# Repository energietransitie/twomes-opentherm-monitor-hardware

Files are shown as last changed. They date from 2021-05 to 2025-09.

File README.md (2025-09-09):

# Twomes OpenTherm Monitor Shield hardware

This repository contains the open hardware design files for the Twomes OpenTherm Monitor device, consisting of:
* a Twomes OpenTherm Monitor Shield with a [WeMos D1 Mini shield](https://www.wemos.cc/en/latest/d1_mini_shield/index.html) form factor, to be placed on;
* a WeMos D1 Mini board, such as the [LilyGO TTGO T7 Mini32 V1.3 ESP32](https://github.com/LilyGO/ESP32-MINI-32-V1.3). 

The OpenTherm Monitor Shield is connected via one pluggable terminal block with screws to connect one wire pair leading to a [boiler that supports OpenTherm](https://www.otgw.tclcode.com/matrix.cgi#boilers) and via another one pluggable terminal block with screws to connect another wire pair leading to a [thermostat that supports OpenTherm](https://www.otgw.tclcode.com/matrix.cgi#thermostats). The Twomes OpenTherm Monitor can upload this measurement data to a Twomes server via Wi-Fi using secure HTTPS.

N.B. This is device  is NOT an OpenTherm gateway; it only monitors OpenTherm traffic and it cannot insert OpenTherm commands to the boiler or thermostat.

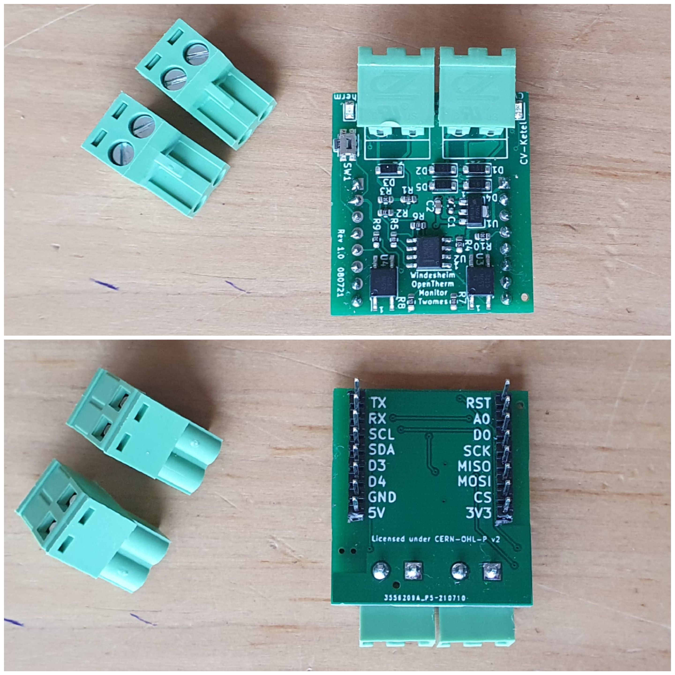
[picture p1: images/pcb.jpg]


## Table of contents
* [General info](#general-info)
* [Producing](#producing)
* [Developing](#developing) 
* [Features](#features)
* [Status](#status)
* [License](#license)
* [Citation](#citation)
* [Credits](#credits)

## General info
This repository contains the open hardware designs files for the Twomes OpenTherm Monitor device, It also includes a `docs` folder with recent printouts of the [schematics](./docs/twomes-opentherm-monitor-hardware-sch-v2.0.pdf) and [PCB layout](./docs/twomes-opentherm-monitor-hardware-pcb-v2.0.pdf). 

The associated firmware that you can run on this device can be found in [this repository](https://github.com/energietransitie/twomes-opentherm-monitor-firmware).

## Producing

### Printed Ciruit Board
To fabricate the printed circuit board you can use various PCB services. 

The folder [pcb/jlcpcb](./pcb/jlcpcb) includes all exported files needed to have the PCBs manufactured by [JLCPCB](https://www.jlcpcb.com). Upload the [zipped gerber files](./pcb/jlcpcb/gerber/gerber-OpenThermMonitorTwomes.zip) to the [JLCPCB quote page](https://cart.jlcpcb.com/quote), select the amount of PCBs and a colour for the silkscreen. All other options can be left on default. If SMT assembly is desired, also select this option before ordering. This will take you to a page where the BOM and POS file can be uploaded. Use the files [BOM-TwomesGateway.csv](./pcb/jlcpcb/assembly/BOM-Twomes-OpenTherm-Monitor.csv) and [CPL-TwomesGateway.csv](./pcb/jlcpcb/assembly/CPL-Twomes-OpenTherm-Monitor.csv).

N.B. The pluggable terminal blocks we used (see [features](#features) are not listed the BOM-*.csv file; they need to be ordered separately other services and soldered manually.

### Enclosure
To fabricate the enclosure you can use your own 3D printer or use a 3D printing service. 

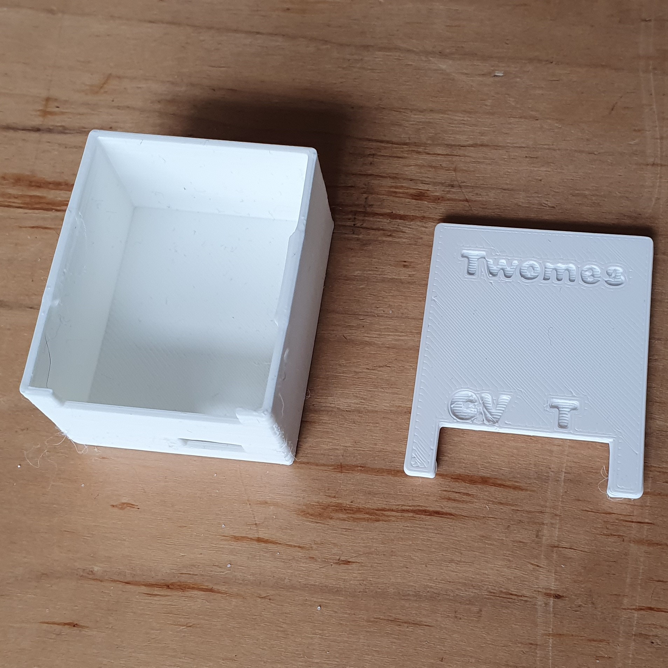
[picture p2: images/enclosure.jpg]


The folder [enclosure/fabrication](./enclosure/fabrication) contains exported STL files for the [case](./enclosure/fabrication/twomes-opentherm-monitor-enclosure-case.stl) and [lid](./enclosure/twomes-opentherm-monitor-enclosure-lid.stl) of the Twomes OpenTherm Monitor. The STL files can be imported into any slicer and turned into G-Code for a 3D printer.

## Developing

### Printed Circuit Board
To change the hardware design of the PCB, you need:
* [KiCad](https://www.kicad.org/download/) installed to change te PCB design. 

The KiCad source files of the PCB can be found in the folder [pcb](./pcb).

To convert the PCBs into a format suitable for fabrication, consult the webpage of your PCB manufacturer of choice. For example, see the [JLCPCB guide on how to export Gerbers](https://support.jlcpcb.com/article/149-how-to-generate-gerber-and-drill-files-in-kicad) and the  [JLCPCB guide how to export the BOM and POS files](https://support.jlcpcb.com/article/84-how-to-generate-the-bom-and-centroid-file-from-kicad). You may also use a KiCad plug-in for this purpose such as [kicad-jlcpcb-tools](https://github.com/Bouni/kicad-jlcpcb-tools).

### Enclosure
To change the hardware design of the enclosure, you need either:
* [Autodesk Fusion 360](https://www.kicad.org/download/) installed (Autodesk provides 30 day free trials and [free one-year educational access](https://www.autodesk.com/education/edu-software/overview?sorting=featured&filters=individual) to its products and services for eligible students, teachers and research staff); 
* or [FreeCAD](https://www.freecadweb.org/), an open source alternative.

The source files of the enclosure can be found in the folder [enclosure](./enclosure). We include both .f3d source files and .step source files we obtained after conversion.

## Features
The Twomes OpenTherm Monitor Shield is a [WeMos D1 Mini shield](https://www.wemos.cc/en/latest/d1_mini_shield/index.html) that features the following main hardware components:
* two terminal blocks [CTB9209/2](https://nl.farnell.com/camdenboss/ctb9209-2/terminal-block-pluggable-2pos/dp/2493642), pluggable into terminal block headers [CTB9359/2](https://nl.farnell.com/camdenboss/ctb9359-2/terminal-block-header-2pos-th/dp/2493694) (one for thermostat, one for boiler), each with two positions;
* two optocouplers that electrically separate the OpenTherm circuit on the shield from the monitoring logic on the shield and the main board: the OpenTherm communication between thermostat and boiler still works even if the main board receives no power via its micro USB port or has crashed;
* recessed button that is positioned behind a pinhole in the device enclosure, which allows the end-user to do a Wi-Fi reset.

To-do:
* change design and JLCPCB files to take advantage of the new [one-sided hand-soldering option for through-hole parts](https://jlcpcb.com/smt-assembly) for the pluggable terminal blocks `J1` and `J2` and the pin headers `P1` and `P2`;

## Status
Project is: _in progress_

## License
The hardware designs in this repository are available under the [CERN-OHL-P v2 license](./LICENSE), Copyright 2022 [Research group Energy Transition, Windesheim University of Applied Sciences](https://windesheim.nl/energietransitie)

## Citation

If you use this repository in your research or work, please cite the following pre-print, which describes the overall NeedForHeat DataGear system of which this repository is a part:

> Ter Hofte, H., & van Ravenzwaaij, N. (2025). *NeedForHeat DataGear: An Open Monitoring System to Accelerate the Residential Heating Transition*. arXiv preprint arXiv:2509.06927. https://doi.org/10.48550/arXiv.2509.06927

**Note:** This is a pre-print submitted on 8 Sep 2025 and has not yet been peer-reviewed. For the full paper, see [https://arxiv.org/abs/2509.06927](https://arxiv.org/abs/2509.06927).

## Credits
This open hardware design is a collaborative effort of:
* Marco Winkelman · [@MarcoW71](https://github.com/MarcoW71)
* Sjors Smit · [@Shorts1999](https://github.com/Shorts1999)

Thanks also go to:
* Henri ter Hofte · [@henriterhofte](https://github.com/henriterhofte)
We use and gratefully acknowlegde the efforts of the makers of the following designs:

* [KiCad Libraries](https://kicad.github.io/), by the KiCad Development Team, licensed under [an adapted version of the CC-BY-SA 4.0 License](https://www.kicad.org/libraries/license/)
* [Opentherm-monitor](https://www.domoticaforum.eu/uploaded/bwired/Open-Termostaat.pdf). In <i>Elektuur, 7-8/2001, pp. 22-23.

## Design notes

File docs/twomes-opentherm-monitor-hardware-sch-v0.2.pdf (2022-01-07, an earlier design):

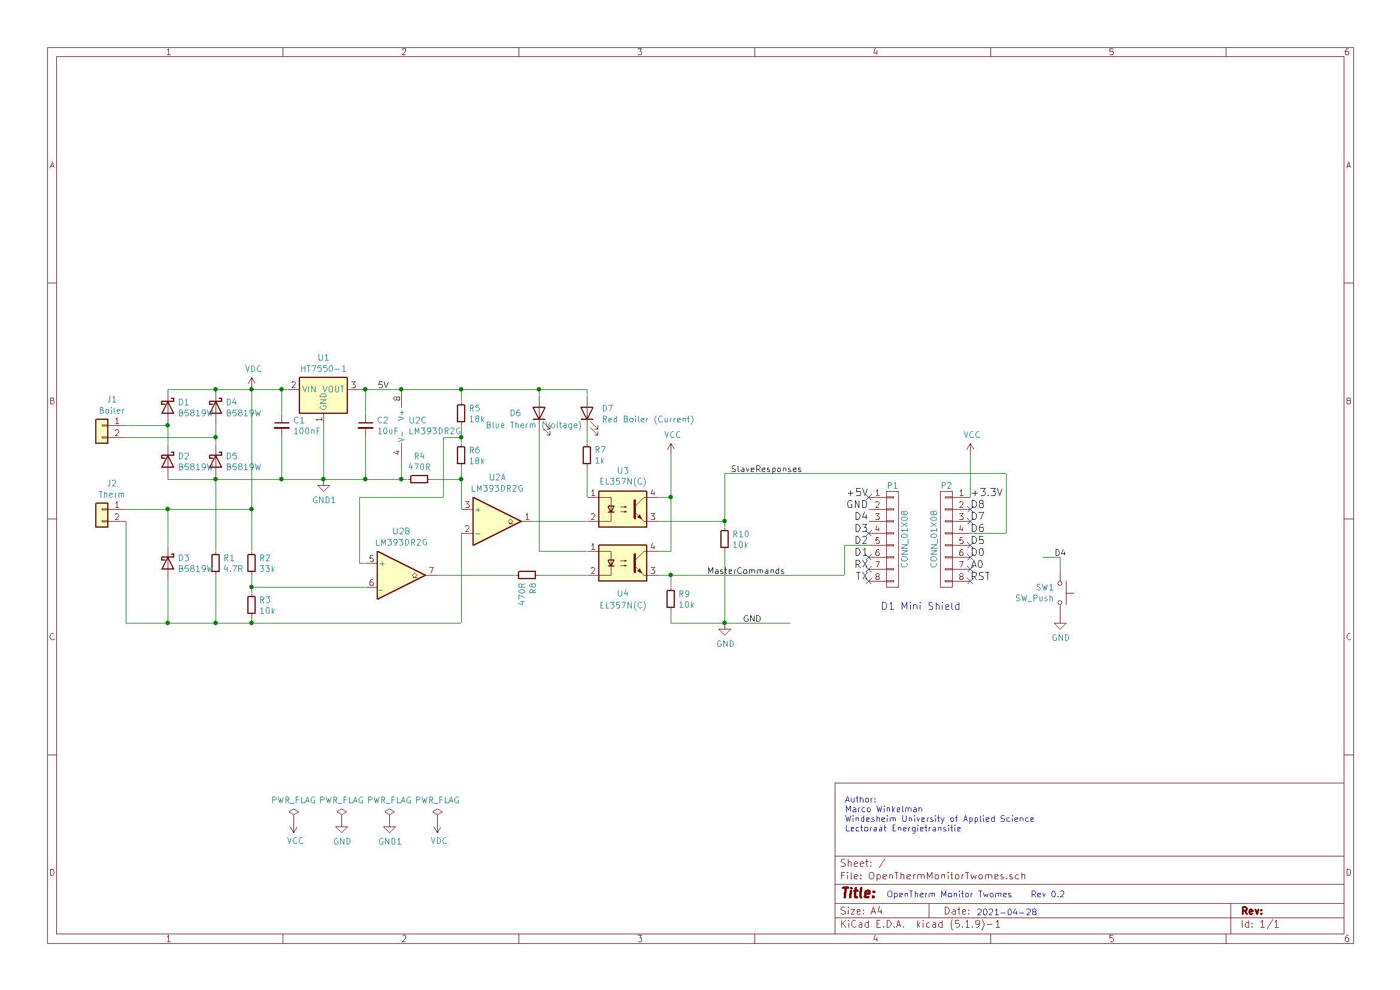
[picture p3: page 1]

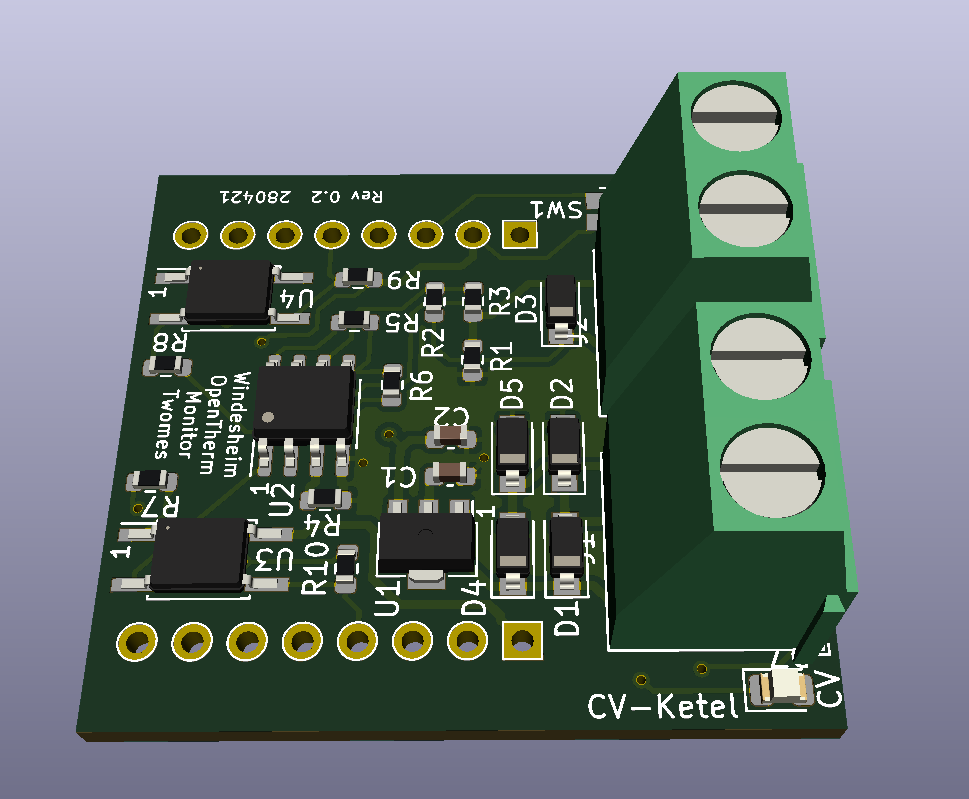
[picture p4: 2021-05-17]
images/twomes-opentherm-monitor-hardware-v0.2-view2.png

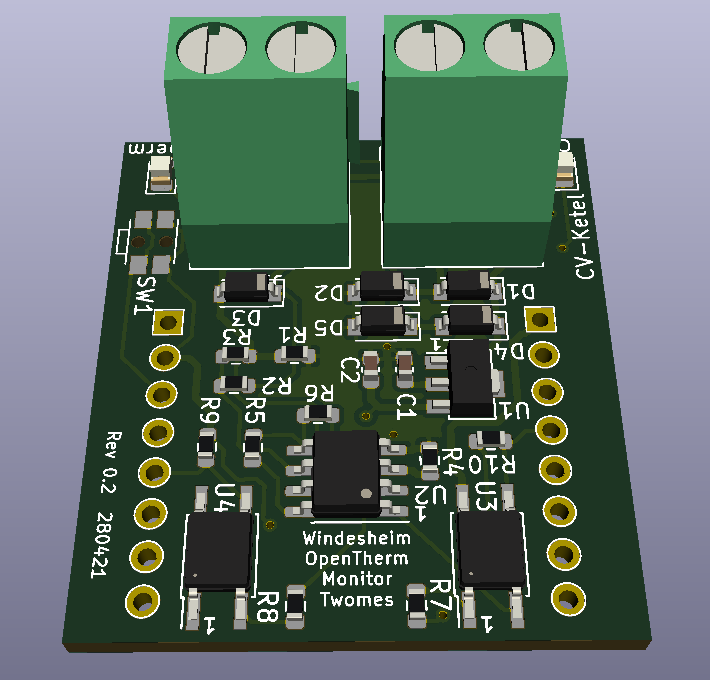
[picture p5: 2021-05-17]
images/twomes-opentherm-monitor-hardware-v0.2-view1.png

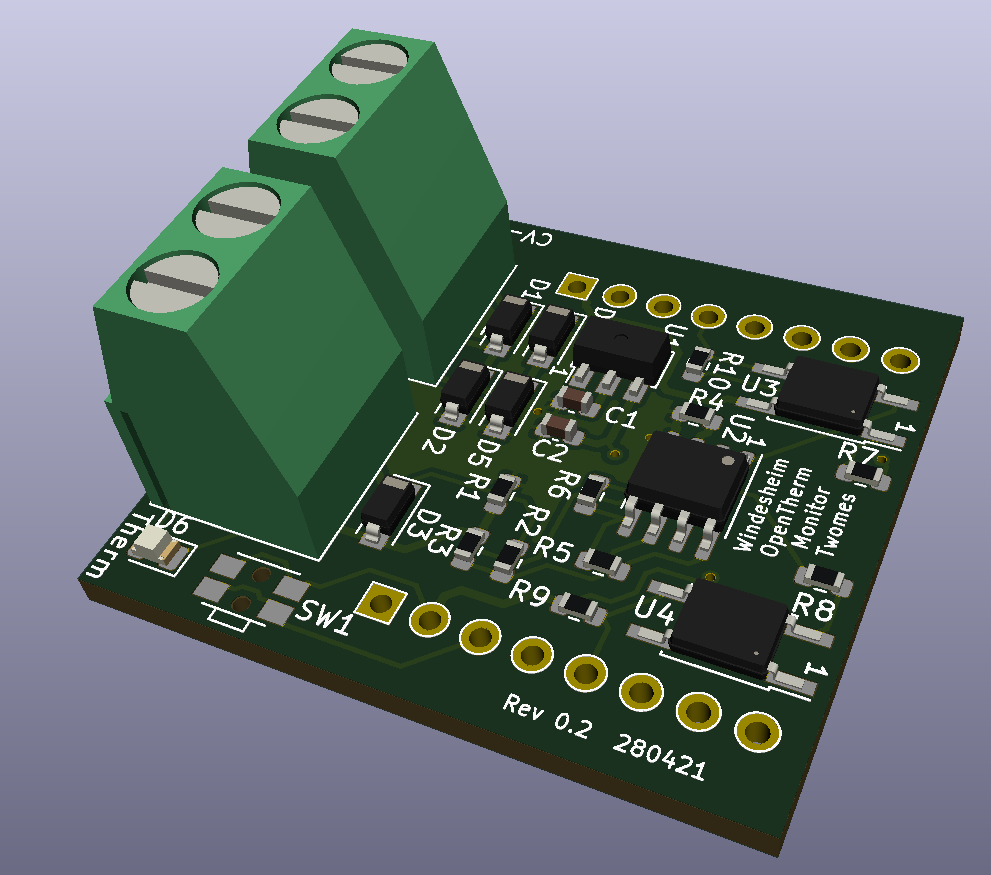
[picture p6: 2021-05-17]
images/twomes-opentherm-monitor-hardware-v0.2-view3.png

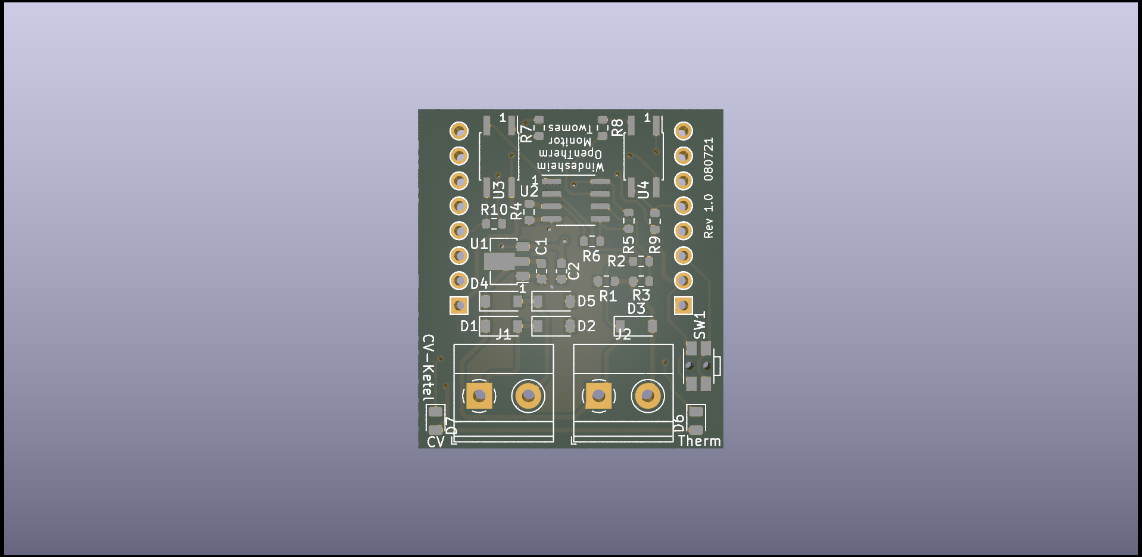
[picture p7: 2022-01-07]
images/twomes-opentherm-monitor-hardware-v1.0-top.png

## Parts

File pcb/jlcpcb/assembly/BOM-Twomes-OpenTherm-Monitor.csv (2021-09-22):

Comment | Designator | Footprint | LCSC
10nF | C1 | Capacitor_SMD:C_0603_1608Metric | C57112
10uF | C2 | Capacitor_SMD:C_0603_1608Metric | C19702
B5819W | D1,D2,D3,D4,D5 | Diode_SMD:D_SOD-123 | C8598
Blue Therm (Voltage) | D6 | LED_SMD:LED_0805_2012Metric | C2293
Red Boiler (Current) | D7 | LED_SMD:LED_0805_2012Metric | C84256
Boiler | J1 | TerminalBlock_Phoenix:TerminalBlock_Phoenix_MKDS-1,5-2_1x02_P5.00mm_Horizontal
Therm | J2 | TerminalBlock_Phoenix:TerminalBlock_Phoenix_MKDS-1,5-2_1x02_P5.00mm_Horizontal
CONN_01X08 | P1,P2 | D1_mini:D1_mini_Pin_Header
4.7R | R1 | Resistor_SMD:R_0603_1608Metric | C23164
33k | R2 | Resistor_SMD:R_0603_1608Metric | C4216
10k | R3,R9,R10 | Resistor_SMD:R_0603_1608Metric | C25804
18k | R5,R6 | Resistor_SMD:R_0603_1608Metric | C25810
1k | R7,R8 | Resistor_SMD:R_0603_1608Metric | C21190
470R | R4 | Resistor_SMD:R_0603_1608Metric | C23179
SW_Push | SW1 | Button_Switch_SMD:SW_SPST_EVQP7C | C115361
HT7550-1 | U1 | Package_TO_SOT_SMD:SOT-89-3 | C16106
LM393DR2G | U2 | Package_SO:SOIC-8_3.9x4.9mm_P1.27mm | C7955
EL357N(C) | U3,U4 | Package_SO:SO-4_4.4x3.6mm_P2.54mm | C29981

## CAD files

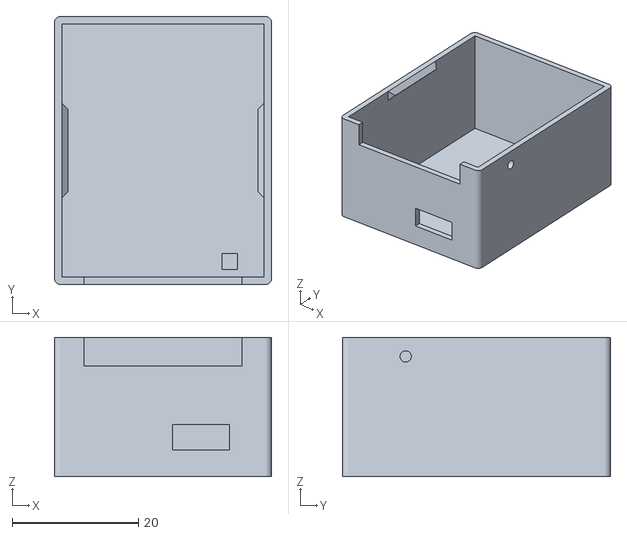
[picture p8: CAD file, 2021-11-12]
enclosure/fabrication/twomes-opentherm-monitor-enclosure-case.stl
34.4 x 42.4 x 22.0

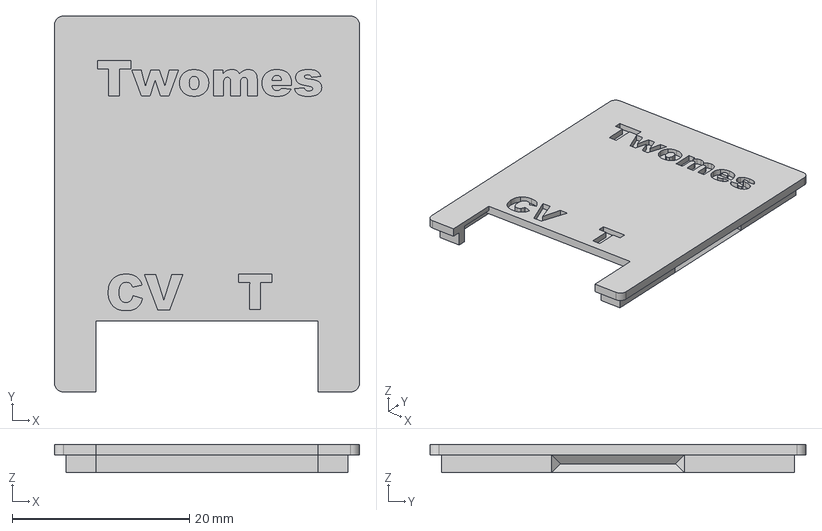
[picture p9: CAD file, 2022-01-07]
enclosure/twomes-opentherm-monitor-enclosure-lid.step
34.4 x 42.4 x 3.20 mm

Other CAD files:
enclosure/fabrication/twomes-opentherm-monitor-enclosure-lid.stl
enclosure/twomes-opentherm-monitor-enclosure-case.step
enclosure/twomes-opentherm-monitor-enclosure.f3d

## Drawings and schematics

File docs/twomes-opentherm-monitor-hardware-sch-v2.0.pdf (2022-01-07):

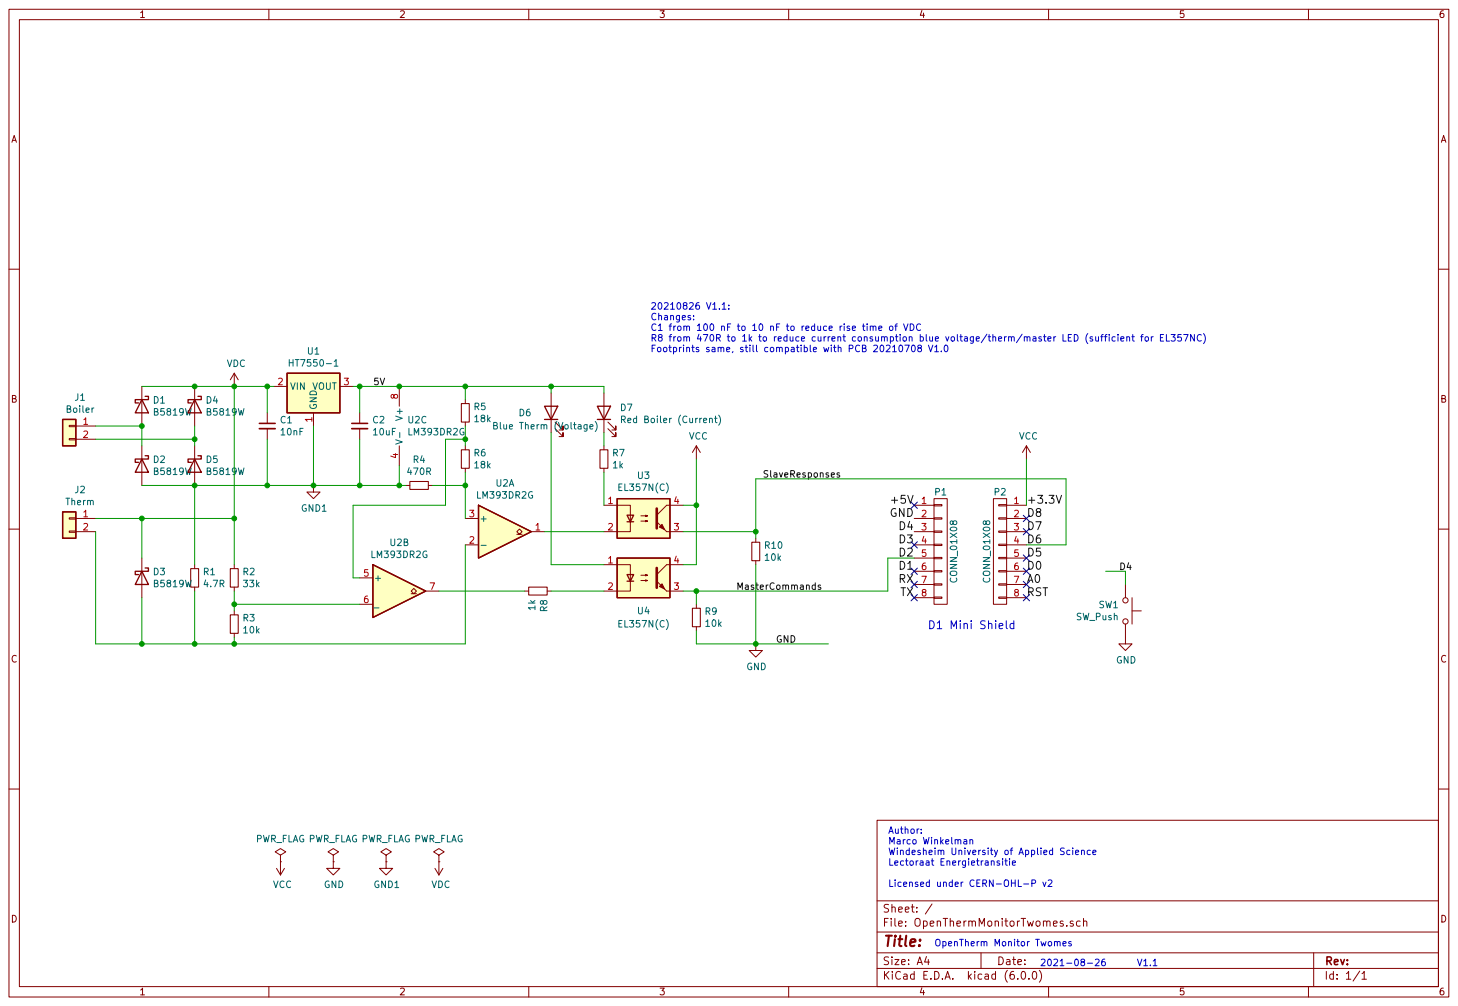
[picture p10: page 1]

20210826 V1.1: Changes: C1 from 100 nF to 10 nF to reduce rise time of VDC

R8 from 470R to 1k to reduce current consumption blue voltage/therm/master LED (sufficient for EL357NC)
Footprints same, still compatible with PCB 20210708 V1.0

1 VIN 2 VOUT 3 U1 VDC HT7550-1 VDC GND

Licensed under CERN-OHL-P v2

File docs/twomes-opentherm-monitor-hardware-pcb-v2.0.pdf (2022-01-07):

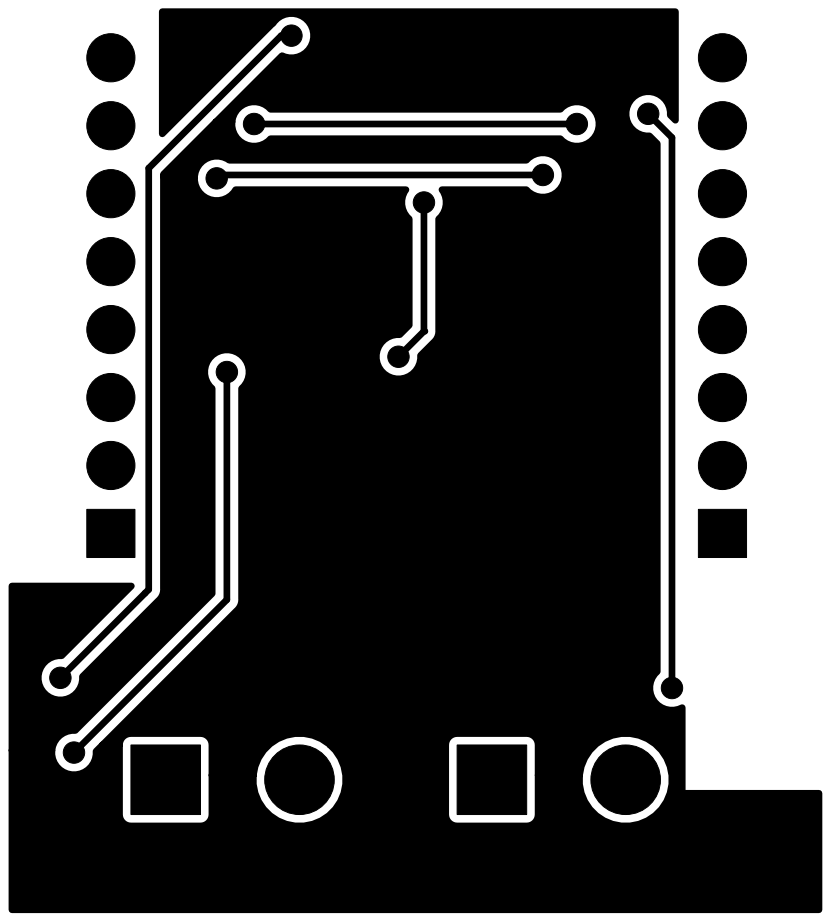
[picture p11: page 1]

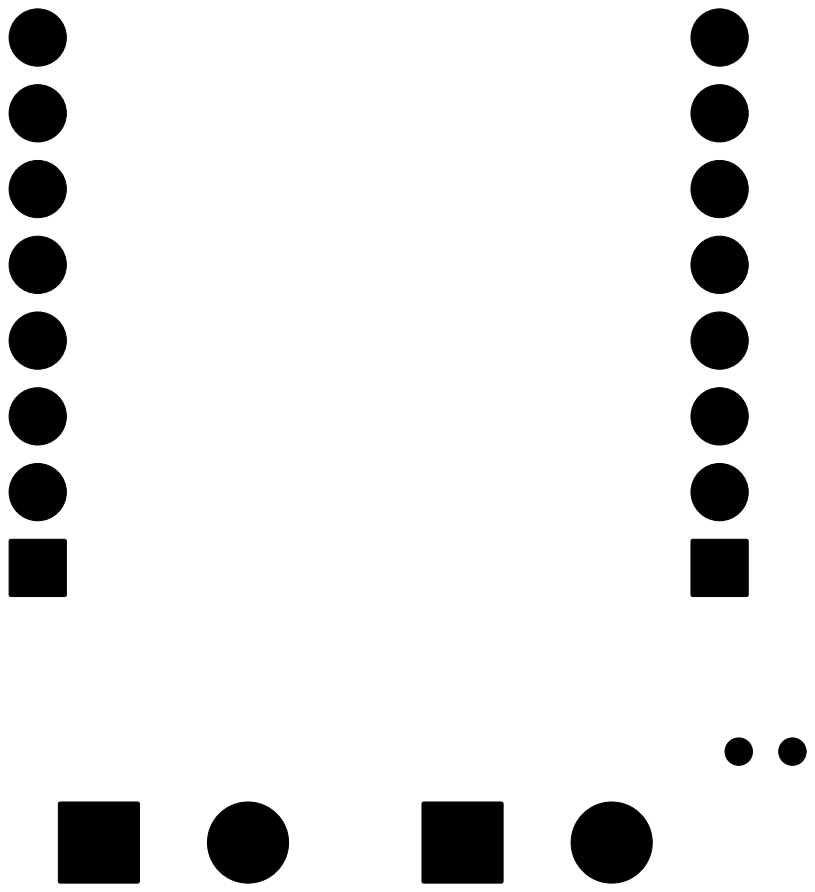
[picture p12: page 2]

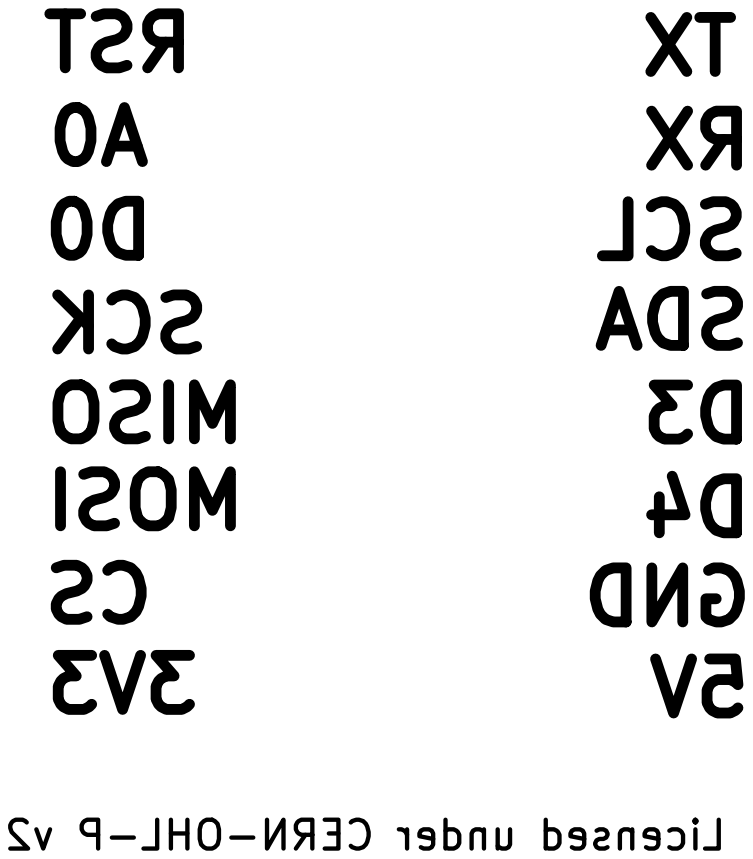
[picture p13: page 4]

Licensed under CERN-OHL-P v2 3V3 CS MOSI MISO

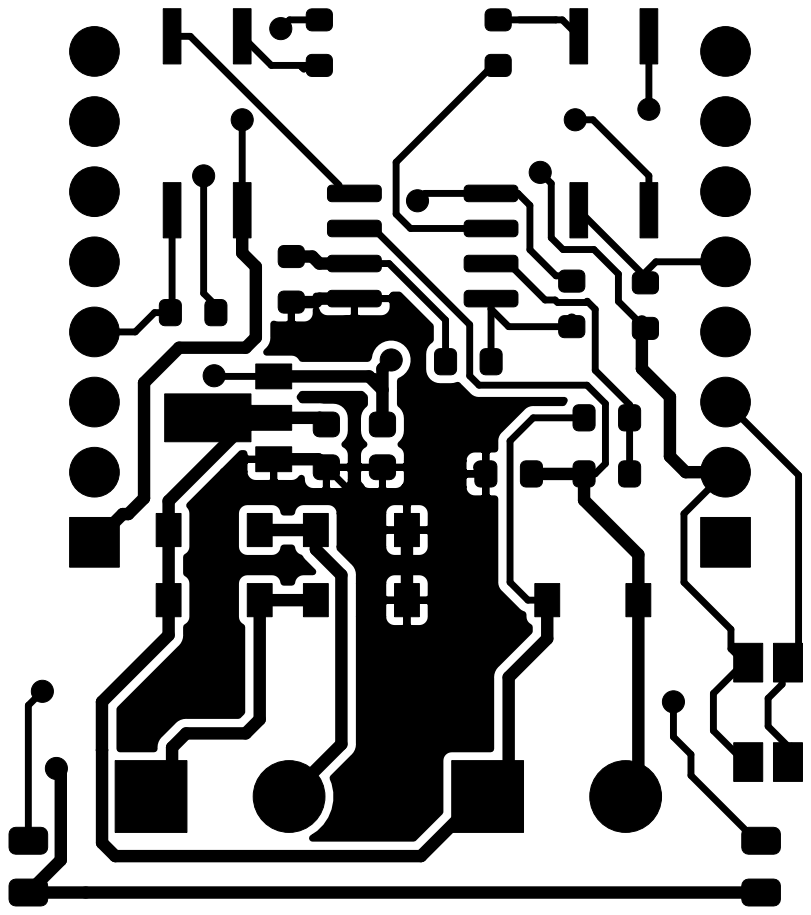
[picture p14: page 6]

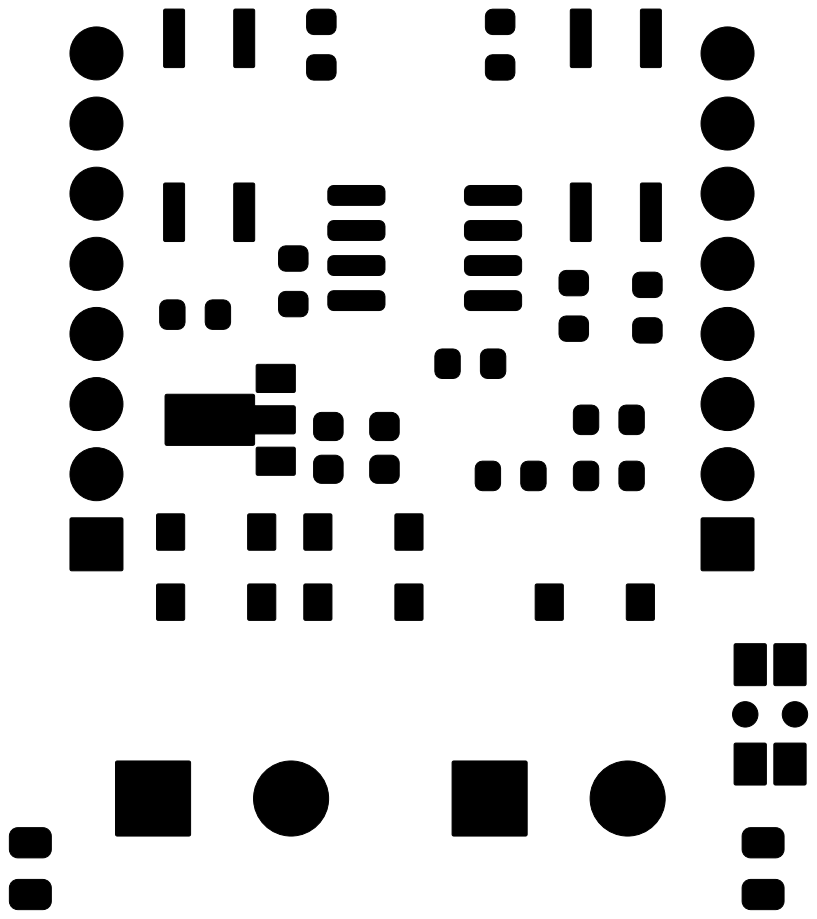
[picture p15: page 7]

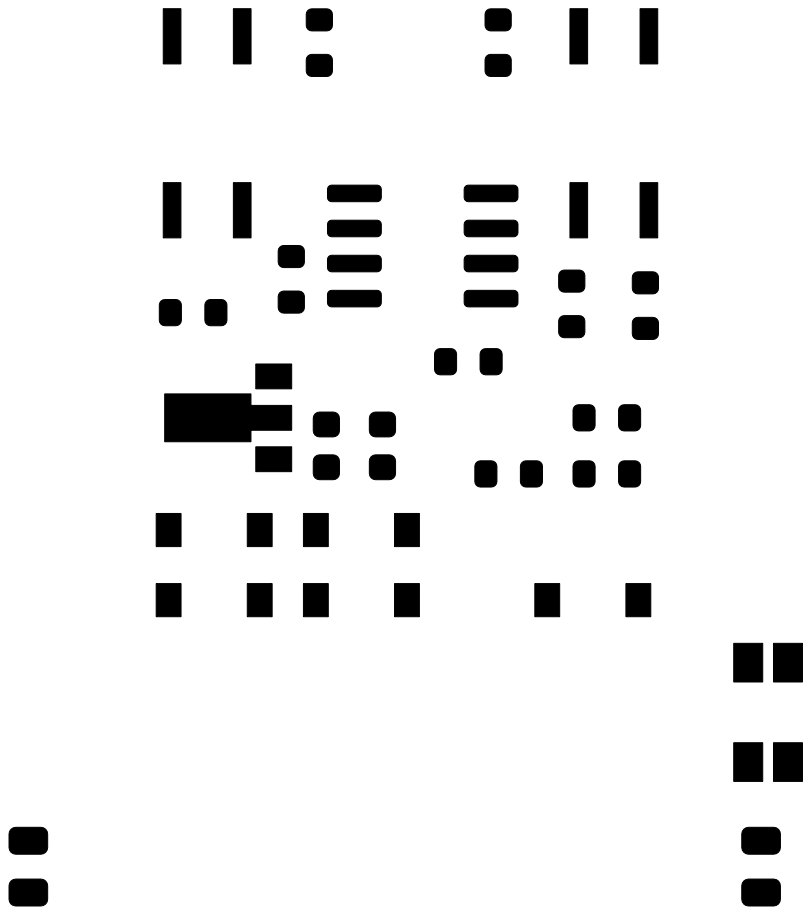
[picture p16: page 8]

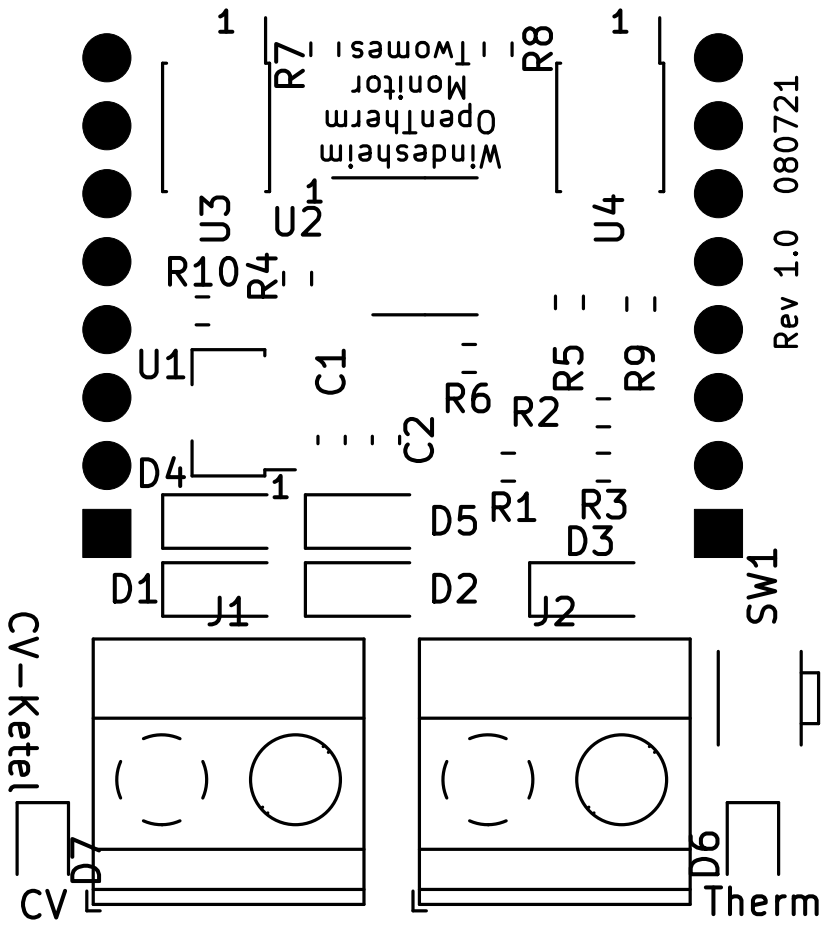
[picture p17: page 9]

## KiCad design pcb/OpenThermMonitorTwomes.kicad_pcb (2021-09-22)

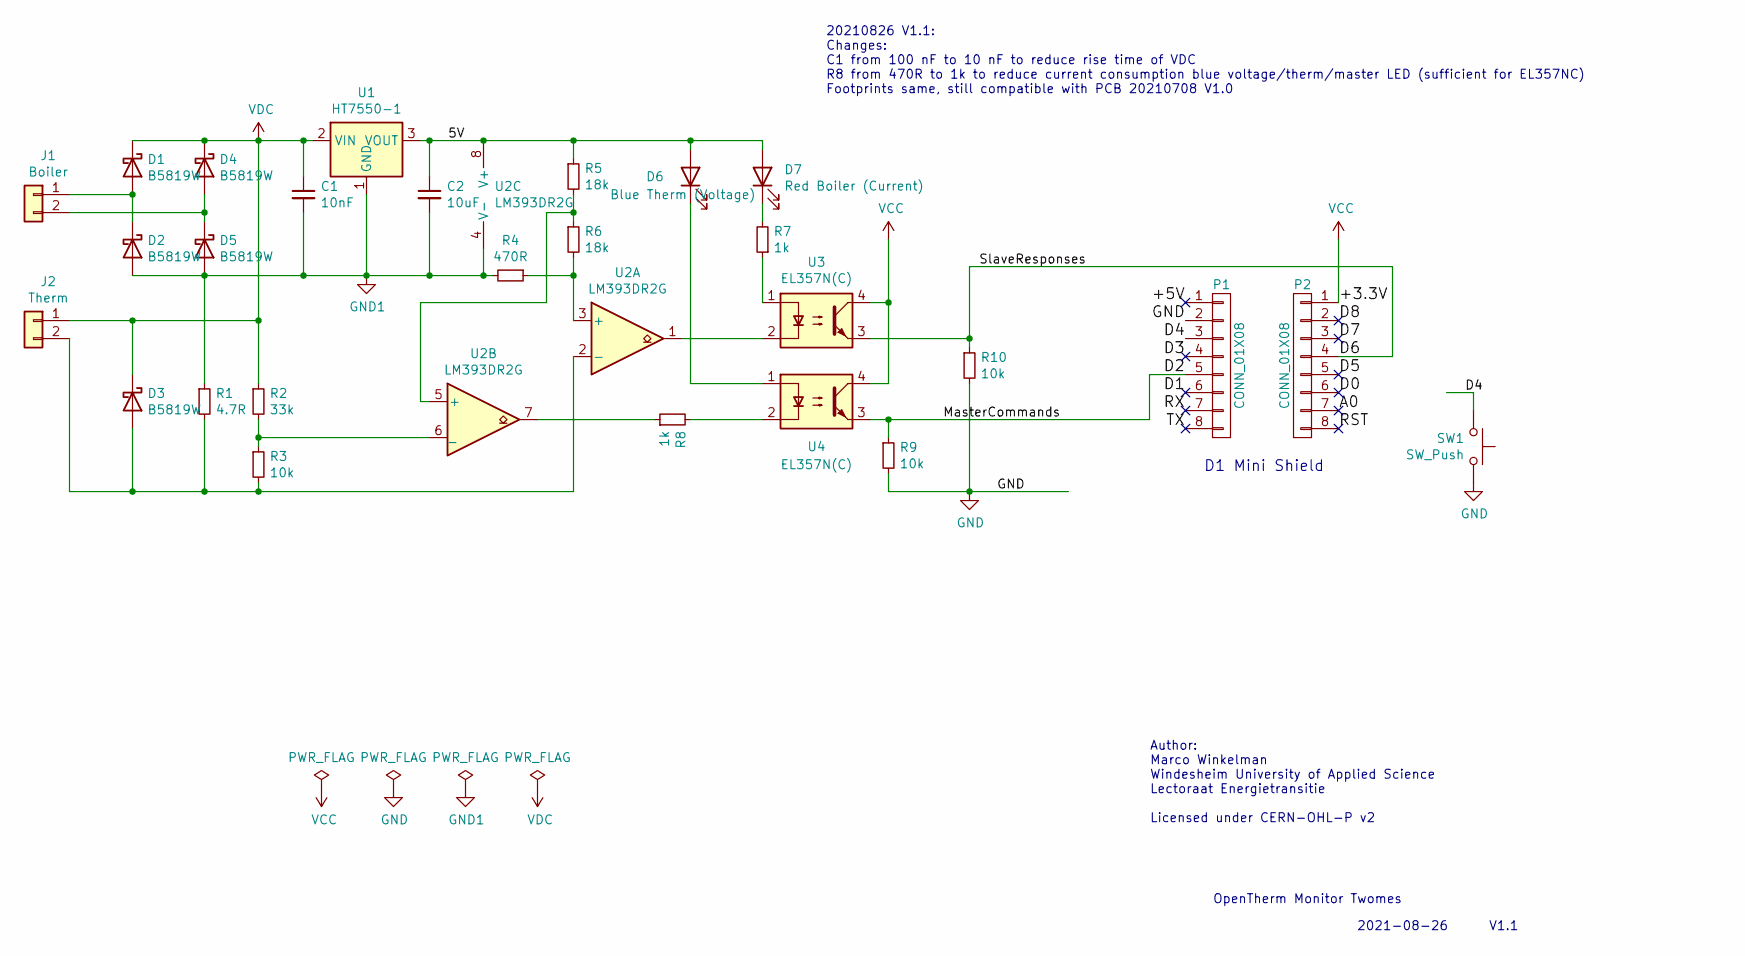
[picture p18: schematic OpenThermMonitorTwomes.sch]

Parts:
C1: 10nF; C_0603_1608Metric
C2: 10uF; C_0603_1608Metric; LCSC C19702
D1, D2, D3, D4, D5: B5819W; D_SOD-123; LCSC C8598
D6: Blue Therm (Voltage); LED_0805_2012Metric; LCSC C2293
D7: Red Boiler (Current); LED_0805_2012Metric; LCSC C84256
J1: Boiler; TerminalBlock_Phoenix_MKDS-1,5-2_1x02_P5.00mm_Horizontal
J2: Therm; TerminalBlock_Phoenix_MKDS-1,5-2_1x02_P5.00mm_Horizontal
P1, P2: CONN_01X08; D1_mini_Pin_Header
R1: 4.7R; R_0603_1608Metric; LCSC C23164
R2: 33k; R_0603_1608Metric; LCSC C4216
R3, R9, R10: 10k; R_0603_1608Metric; LCSC C25804
R4: 470R; R_0603_1608Metric; LCSC C23179
R5, R6: 18k; R_0603_1608Metric; LCSC C25810
R7, R8: 1k; R_0603_1608Metric; LCSC C21190
SW1: SW_Push; SW_SPST_EVQP7C; LCSC C115361
U1: HT7550-1; SOT-89-3; LCSC C16106
U2: LM393DR2G; SOIC-8_3.9x4.9mm_P1.27mm; LCSC C7955
U3, U4: EL357N(C); SO-4_4.4x3.6mm_P2.54mm; LCSC C29981

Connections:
/5V: C2.1, D6.2 (A), D7.2 (A), R5.1, U1.3 (VOUT), U2.8 (V+)
/+5V: P1.1
/A0: P2.7
/D0: P2.6
/D1: P1.6
/D2: P1.5, R9.1, U4.3
/D3: P1.4
/D4: P1.3, SW1.2
/D5: P2.5
/D6: P2.4, R10.1, U3.3
/D7: P2.3
/D8: P2.2
/RST: P2.8
/RX: P1.7
/TX: P1.8
GND: P1.2, R9.2, R10.2, SW1.1
GND1: C1.2, C2.2, D2.2 (A), D5.2 (A), R1.1, R4.2, U1.1 (GND), U2.4 (V-)
unnamed: D1.2 (A), D2.1 (K), J1.1
unnamed: D3.2 (A), J2.2, R1.2, R3.2, U2.2 (-)
unnamed: D4.2 (A), D5.1 (K), J1.2
unnamed: D6.1 (K), U4.1
unnamed: D7.1 (K), R7.2
unnamed: R2.2, R3.1, U2.6 (_)
unnamed: R4.1, R6.2, U2.3 (+)
unnamed: R5.2, R6.1, U2.5 (+)
unnamed: R7.1, U3.1
unnamed: R8.1, U2.7
unnamed: R8.2, U4.2
unnamed: U2.1, U3.2
VCC: P2.1, U3.4, U4.4
VDC: C1.1, D1.1 (K), D3.1 (K), D4.1 (K), J2.1, R2.1, U1.2 (VIN)

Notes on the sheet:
D1 Mini Shield
OpenTherm Monitor Twomes
Author: Marco Winkelman Windesheim University of Applied Science Lectoraat Energietransitie Licensed under CERN-OHL-P v2
20210826 V1.1: Changes: C1 from 100 nF to 10 nF to reduce rise time of VDC R8 from 470R to 1k to reduce current consumption blue voltage/therm/master LED (sufficient for EL357NC) Footprints same, still compatible with PCB 20210708 V1.0
2021-08-26 V1.1

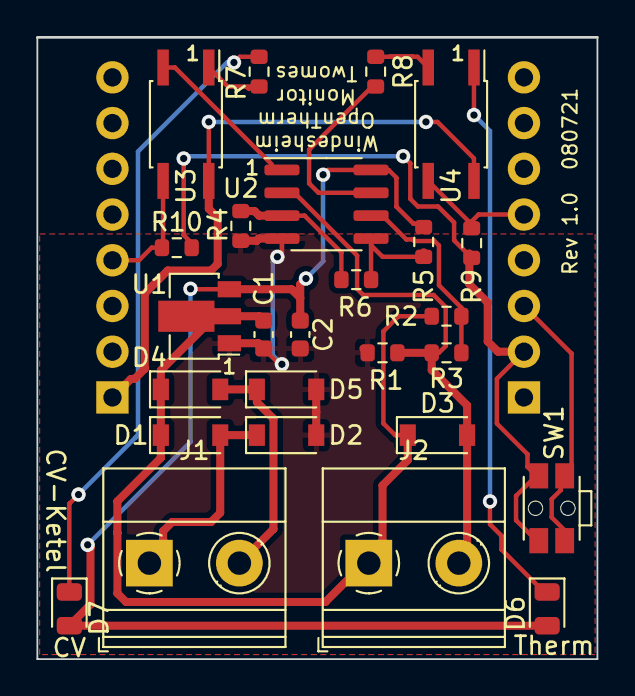
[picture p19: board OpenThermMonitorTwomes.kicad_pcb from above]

Board: 2 copper layers, 31.1 x 34.5 mm, 28 parts (0 on the bottom side), 20 nets.

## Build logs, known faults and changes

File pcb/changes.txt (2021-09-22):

20210708 V1.0: M.Winkelman Twomes Windesheim
Initial version. Optimized for JLCPCB basic parts
________________________________________________________________________________________________________
20210826 V1.1: M.Winkelman Twomes Windesheim
Changes:  
C1 from 100 nF to 10 nF to reduce rise time of VDC
R8 from 470R to 1k to reduce current consumption blue voltage/therm/master LED (sufficient for EL357NC)
Footprints same, still compatible with PCB 20210708 V1.0
________________________________________________________________________________________________________

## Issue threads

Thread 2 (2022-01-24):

OpenTherm Monitor interferes with Remeha (Quinta 28c, perhaps also Avanta) when combined with certain (power hungy?) thermostats

henriterhofte, 2022-01-24:
Result is that some critical thermostats don't work properly.

Examples of boiler -- thermostat combinations that don't work properly:
- Remeha Quinta 28c -- Honeywell R8810A1018 wireless OpenTherm Bridge (combined with any Honeywell Wireless Modulation thermostat, e.g. Round Wireless Modulation [Y87RF1004/87RF2008]
- Remeha Avanta -- Remeha Celcia 20
- Remeha Tzerr Plus -- Remeha iSense
- Remeha Tzerra Plus -- Google Nest V3 OpenTherm

Examples of boiler -- thermostat combinations that DO work properly:
- Remeha Tzerra - Remeha qSense
- Remeha Avanta - Tado

Hypothesis: OpenTherm Monitor consumes too much power for these thermostats. Investigate which of the components may not adhere properly to OpenTherm standards (if any).

Possible solutions:
- make detection circuit consume even less less power (e.g. move LEDs to powered side; which also reduces the chance that people think the unit is properly powered and forget to provide power the OpenTherm Monitor).
- make a circuit that can actively power the thermostat connector of OpenTherm (assuming the OpenTherm monitor is fed via the 5V USB port (either by an 230V-5V adapter or by a large enough power bank)

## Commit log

2021-05-17 OpenTherm HW KiCad design rev 0.2
    [OpenThermMonitorTwomes-B_Cu.gbr, OpenThermMonitorTwomes-B_Mask.gbr, OpenThermMonitorTwomes-B_Paste.gbr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]
2021-09-22 V1.1 Fixed risetime issue
    [OpenThermMonitorTwomes-B_Cu.gbl, OpenThermMonitorTwomes-B_Mask.gbs, OpenThermMonitorTwomes-B_Paste.gbp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]
2021-09-22 Generated new position files for PCB assembly to reflect updated components in v1.1 schematic
    [OpenThermMonitorTwomes.kicad_pcb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]
2021-11-12 new enclosures with text
    [OpenThermCase.stl, OpenThermEnclosure.f3d, OpenThermTop.stl]
2022-01-04 directory restructure and update readme
    [OpenThermCase.stl, OpenThermEnclosure.f3d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]
2022-01-06 restructure repository and update README
    [BOM-Twomes-OpenTherm-Monitor.csv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]
